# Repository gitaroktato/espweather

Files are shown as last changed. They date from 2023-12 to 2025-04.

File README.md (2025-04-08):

# An ESP8266 -based Weather Station

## Realtime Measurements
View it on ThikgSpeak (https://thingspeak.com/channels/2390966)

## Schematic
EasyEDA schematics
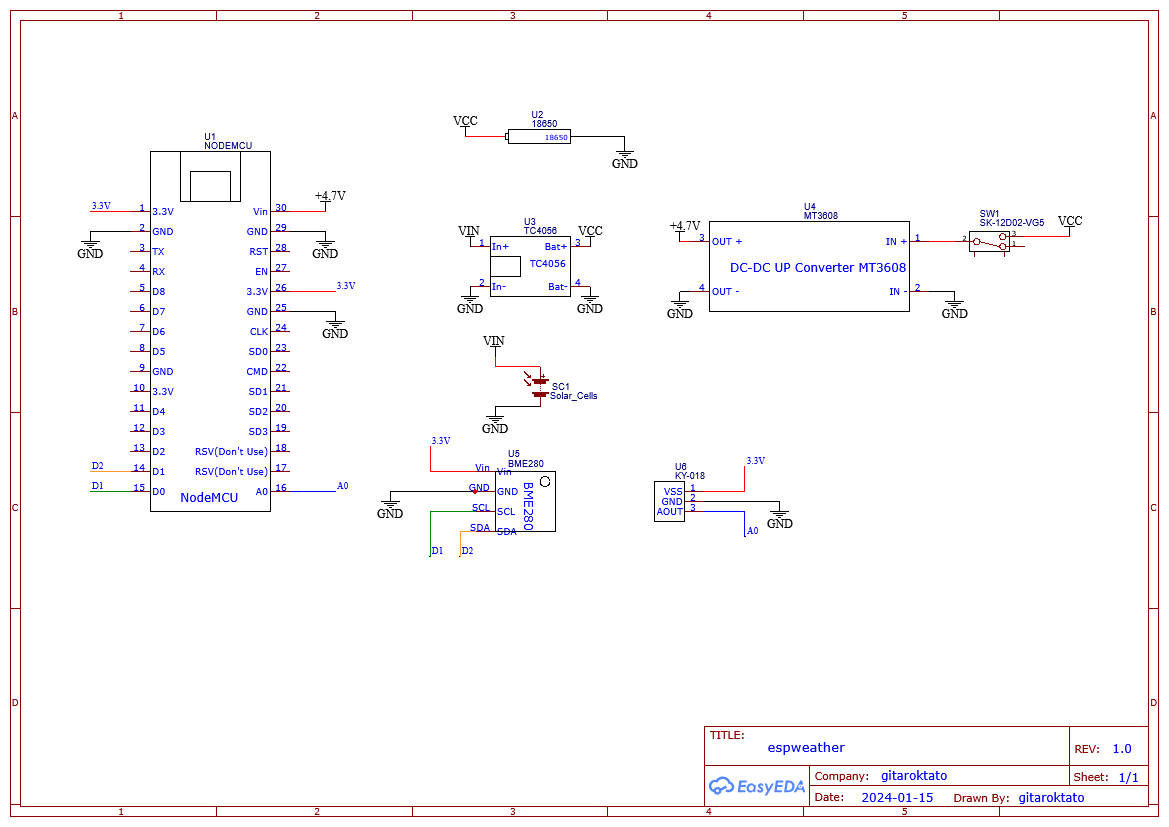
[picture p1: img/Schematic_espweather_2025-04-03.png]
schematic


Fritzing diagram
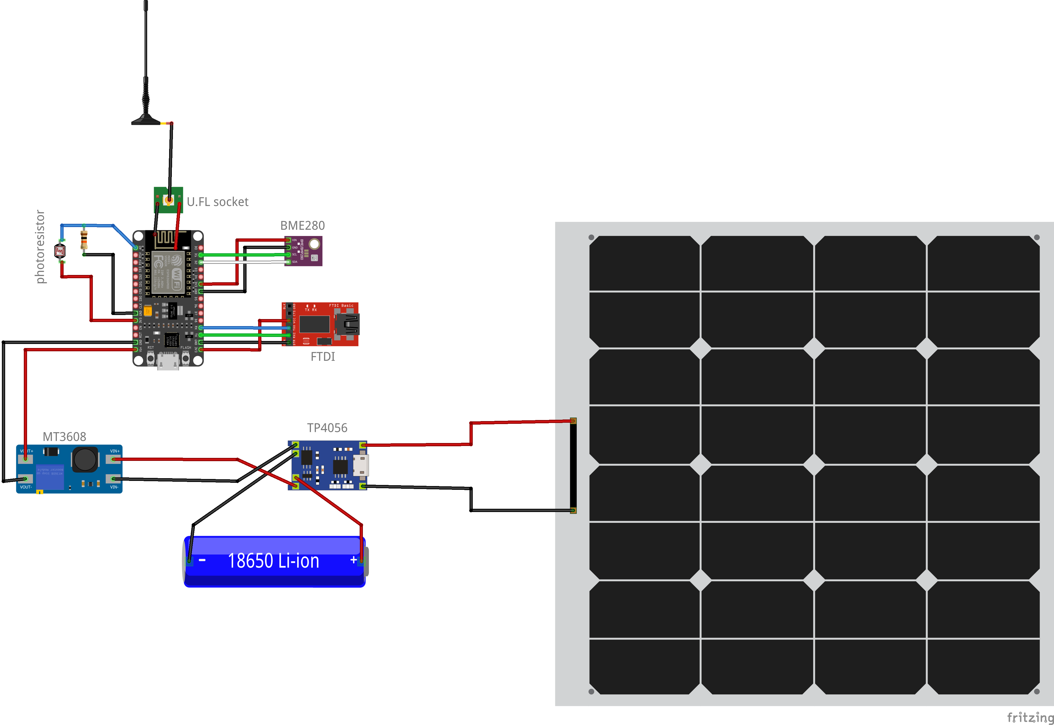
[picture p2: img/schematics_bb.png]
schematic


## Look & Feel

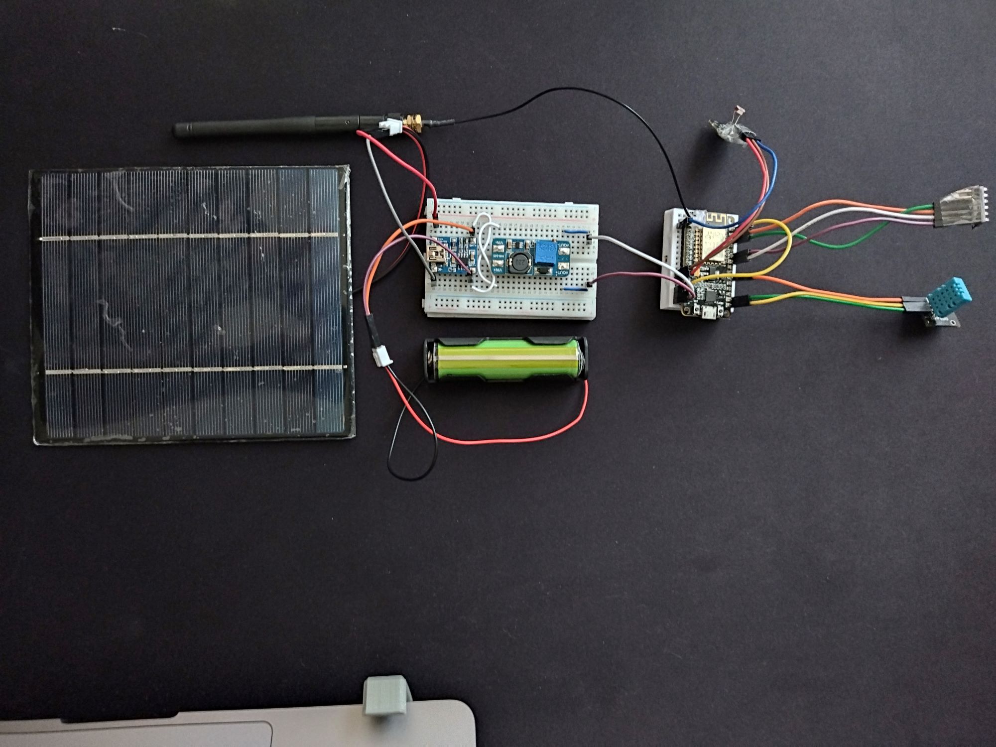
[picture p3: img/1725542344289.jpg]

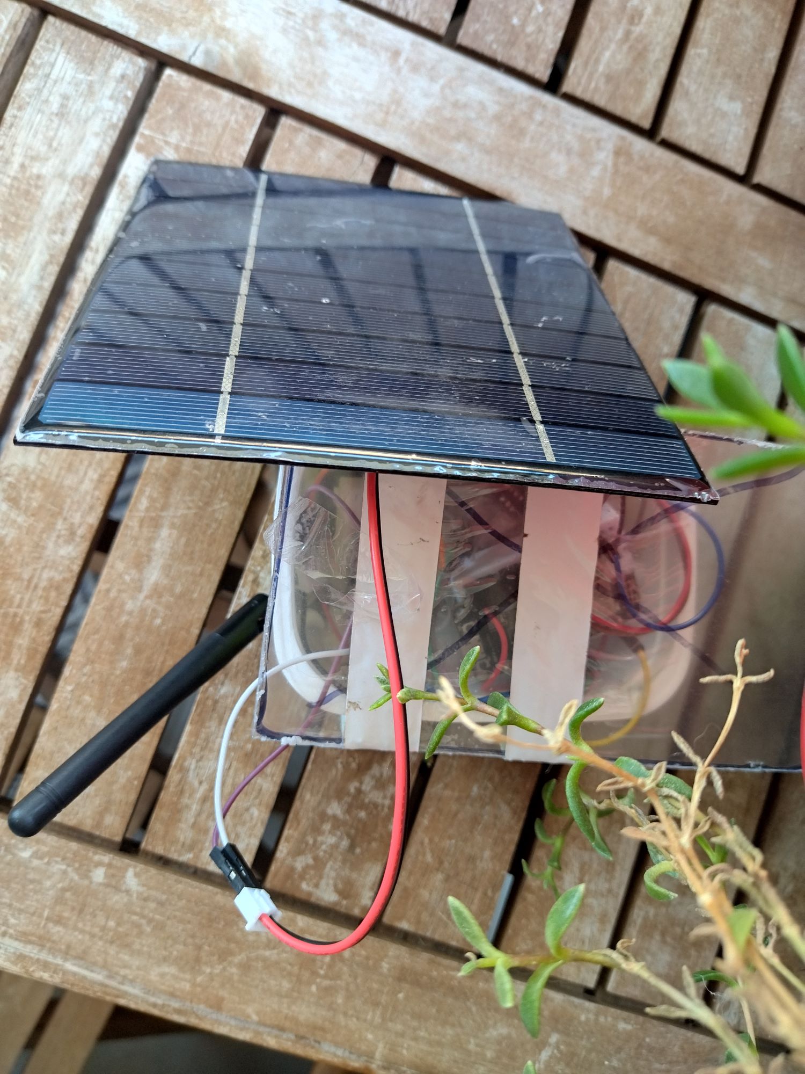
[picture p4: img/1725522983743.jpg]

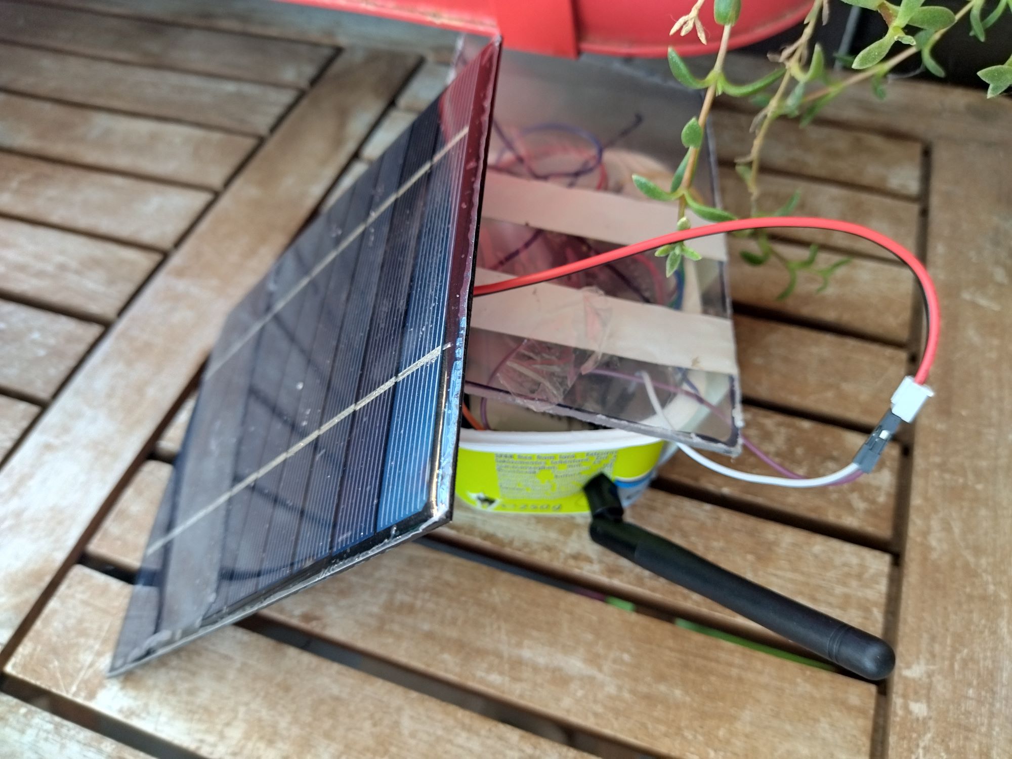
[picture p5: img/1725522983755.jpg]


## Energy Consumption and Battery Life
Powered by a [18650 battery with the capacity of 3300mAh](https://www.hestore.hu/prod_10039174.html?lang=en).

| State | Consumption | Period |
| -- | -- | -- |
| Wake - with onboard LEDs ON | 100mA | ~1s |
| Sleep - with onboard LEDs ON | 30mA | ~1s |
| Wake - with onboard LEDs OFF | 160mA | ~5s |
| Deep Sleep - with onboard LEDs OFF | 4mA | ~15 min |

### Battery life estimation
Over an hour period we expect to have 4 times `5s` spent on reporting. During these intervals the energy consumption is `160mA`.
In the remaining time we expect to consume `4mA`. This period lasts for `3600s - (4 * 5s)) = 3580s`.

The total battery consumption over an hour is around `160mA * 5s * 4` for the reporting periods, and `4mA * 3580s` for the deep sleep.
**Consumption over an hour is** `(3200mA + 14320mA) / 3600s ~= 4.86mA`

On average expected reporting time should be **28 days (3300mAh / ~4.86mA / 24h)**!

- Current reporting time without deep sleep and both LEDs blinking ~22 hrs
- Last reporting time with deep sleep ~3 days (on balcony, but suspecting continuous connection problems. See issue #12)
- Last reporting time with deep sleep ~14 days (on balcony with a step-up converter)

### Circuit Bending
#### Cutting off the onboard USB UART bridge
In order to reduce power consumption Node MCU requires hardware modifications. This is mainly due to the fact, that the CP2102 UART bridge is getting powered even if we use the 3V3 pin. The estimated power consumption is around `~15mA`. This can be done with an exacto knife.

Programming and flashing firmware for the ESP8266 can be done with an FTDI chip (see [Fritzing diagram](#schematic))

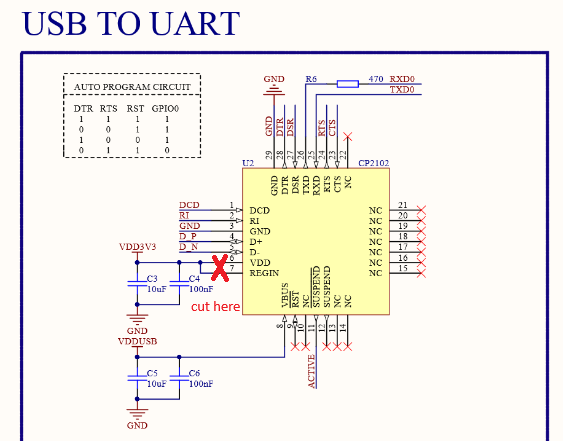
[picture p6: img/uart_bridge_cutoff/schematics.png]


First we scrape off the resin from the surface to reveal the ciruit.



Next we break the connection.



- More about this topic is available [over here](https://tinker.yeoman.digital/2016/05/29/running-nodemcu-on-a-battery-esp8266-low-power-consumption-revisited/).
- See the schematics [over here](https://github.com/nodemcu/nodemcu-devkit-v1.0/blob/master/NODEMCU_DEVKIT_V1.0.PDF).

#### External SMA antenna
Another improvement we can do is to include an external antenna. You can solder it directly, or use an U.FL connector for nicer look & feel.

If you want to solder in an U.FL socket, you need to arrange it the following way. Start with cutting off the connection for the onbard antenna.



Arrange the U.FL socket the following way:



For the direct wire connection you can secure your work usgin hot glue. See the images below:

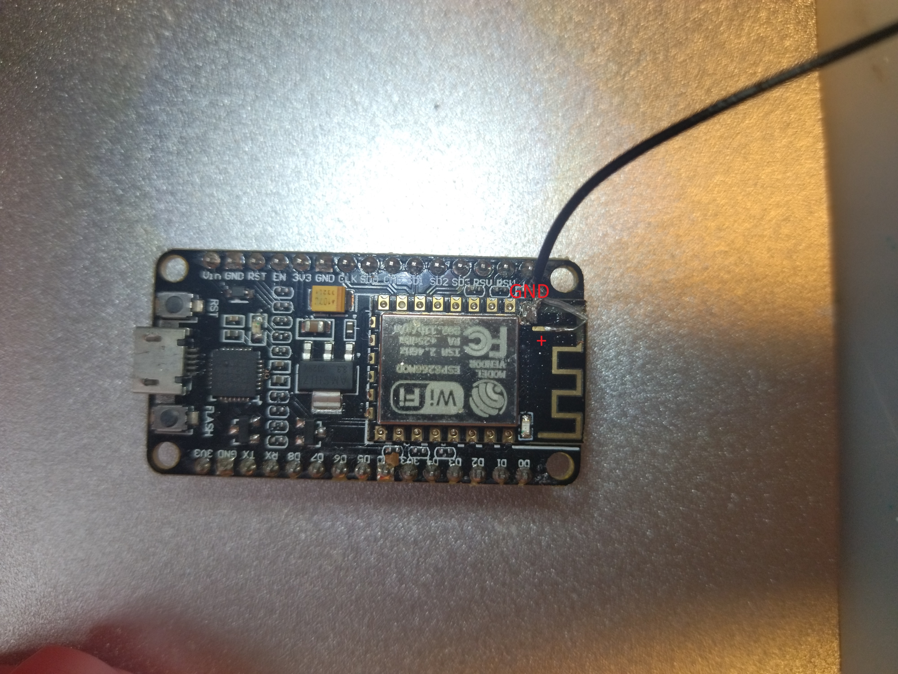
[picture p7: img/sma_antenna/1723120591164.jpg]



More about this topic is available on [YouTube](https://www.youtube.com/watch?v=RYlvXglUnGc) and on other sites, [here](https://community.home-assistant.io/t/how-to-add-an-external-antenna-to-an-esp-board/131601) and [here](https://www.hackster.io/simon-vavpotic/esp32-and-esp8266-external-antenna-f28e6b).

### Measurements
Measurements made using an oscilloscope through a shunt resistor of 1 Ohm. See the setup below:



Wake - with onboard LEDs ON shows 60mA usage on average.



Deep sleep with periodic wake times - shows `17mA` usage on average with 80mA peak. See the table above with estimated battery life.



Deep sleep after hardware modifications - shows `4mA` usage on average with 160mA peak. See the table above with estimated battery life.

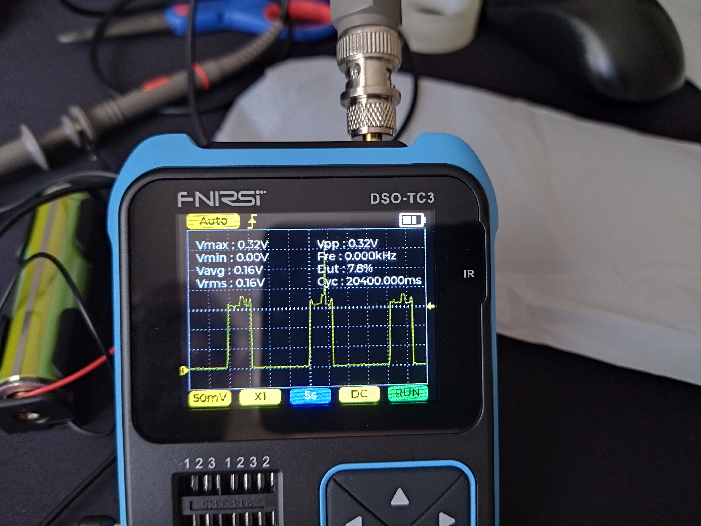
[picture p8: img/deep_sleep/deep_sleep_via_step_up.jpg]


## References

- https://randomnerdtutorials.com/esp8266-pinout-reference-gpios/
- https://randomnerdtutorials.com/esp8266-bme280-arduino-ide/
- https://arduinomodules.info/ky-015-temperature-humidity-sensor-module/
- https://nothans.com/thingspeak-tutorials/esp8266/building-the-internet-of-things-with-the-esp8266-wi-fi-module-and-thingspeak
- https://github.com/nothans/thingspeak-esp-examples/blob/master/examples/RSSI_to_ThingSpeak.ino

### 3D Designs
- https://www.thingiverse.com/thing:144665
- https://www.thingiverse.com/thing:4805867
- https://www.thingiverse.com/thing:1718334
- https://www.thingiverse.com/thing:1985125

### Powering ESP8266
- https://hackaday.io/project/167731-testing-cheap-linear-li-ion-chargers-for-solar
- https://forum.arduino.cc/t/how-to-power-esp8266-ch304-with-18650-li-ion-battery/1179338/14
- https://randomnerdtutorials.com/esp8266-voltage-regulator-lipo-and-li-ion-batteries/
- https://randomnerdtutorials.com/power-esp32-esp8266-solar-panels-battery-level-monitoring/
- https://www.youtube.com/watch?v=f2yMs-JAyQM
- https://www.youtube.com/watch?v=ttyKZnVzic4
- https://youtu.be/6DY767kQnUM?si=SXygTiLH4zx0RgAH

### Power Consumption Comparison
- https://blog.voneicken.com/2018/lp-wifi-esp-comparison/

### Deep Sleep
- https://randomnerdtutorials.com/esp8266-deep-sleep-with-arduino-ide/
- https://www.instructables.com/ESP8266-Pro-Tips
- https://arduinodiy.wordpress.com/2020/01/18/very-deepsleep-and-energy-saving-on-esp8266/

### Photocells
- https://www.mouser.com/datasheet/2/737/photocells-932884.pdf

### FTDI Upload for ESP8266
- https://community.platformio.org/t/esp32-pio-unified-debugger/4541/19

### BME280
- https://randomnerdtutorials.com/esp8266-bme280-arduino-ide

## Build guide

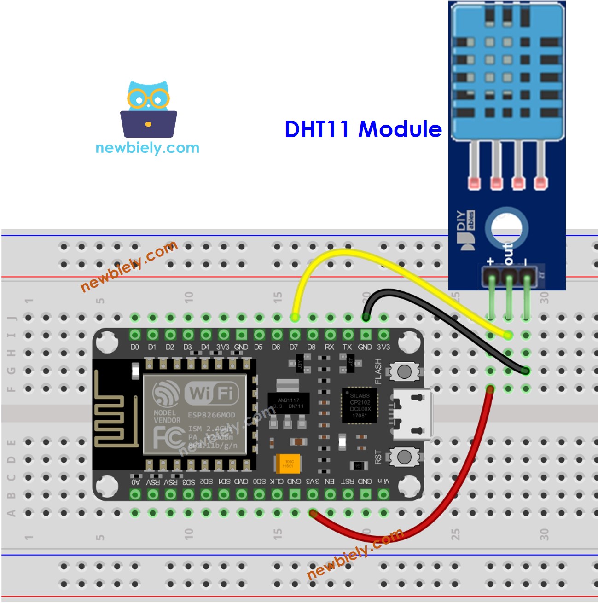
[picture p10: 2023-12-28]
img/esp8266-dht11-temperature-humudity-module-wiring-diagram.jpg

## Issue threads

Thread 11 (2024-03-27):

Fix deep sleep issue with WiFi connectivity

gitaroktato, 2024-03-27:
The WiFi seems to attempt reconnection continuously after waking up from a deep sleep.

**Things to try**
- Lower deep sleep period
- Re-evaluate WiFi connection approach

gitaroktato, 2024-08-14:
Reference guide: https://www.espressif.com/sites/default/files/9b-esp8266-low_power_solutions_en_0.pdf

gitaroktato, 2024-08-21:
Detailed post with hardware hack: https://tinker.yeoman.digital/2016/05/29/running-nodemcu-on-a-battery-esp8266-low-power-consumption-revisited/

gitaroktato, 2024-08-21:
NodeMCU schematics:
https://github.com/nodemcu/nodemcu-devkit-v1.0/blob/master/NODEMCU_DEVKIT_V1.0.PDF

Closed 2024-08-29.

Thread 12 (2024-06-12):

Add extended antenna to ESP8266 NodeMCU

gitaroktato, 2024-06-12:
https://peterneufeld.wordpress.com/2021/10/14/esp32-range-extender-antenna-modification/
https://www.youtube.com/watch?app=desktop&v=Mx0uEBPu7_8
https://community.home-assistant.io/t/how-to-add-an-external-antenna-to-an-esp-board/131601/13

SMA socket soldering:
https://www.youtube.com/watch?v=RYlvXglUnGc

Pinouts:
https://community.home-assistant.io/t/how-to-add-an-external-antenna-to-an-esp-board/131601
https://www.hackster.io/simon-vavpotic/esp32-and-esp8266-external-antenna-f28e6b

gitaroktato, 2024-08-12:
Range tests:
https://www.youtube.com/watch?v=KYLN9qH0C84

Closed 2024-08-29.

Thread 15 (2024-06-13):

Use an LDO regulator for lower deep sleep power consumption

oresztesz-margaritisz-epam, 2024-06-13:
See: https://randomnerdtutorials.com/esp8266-voltage-regulator-lipo-and-li-ion-batteries/

gitaroktato, 2024-08-12:
Interesting experiment:
https://www.youtube.com/watch?v=IYuYTfO6iOs

gitaroktato, 2024-08-13:
Check the datasheet for using the internal LDO
http://www.advanced-monolithic.com/pdf/ds1117.pdf

gitaroktato, 2025-03-31:
See [XC6206](https://product.torexsemi.com/system/files/series/xc6206.pdf) datasheet

gitaroktato, 2025-04-03:
18650 discharge capacity

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

gitaroktato, 2025-04-08:
[This example code](https://gitlab.com/diy_bloke/verydeepsleep_bme280_sendtodb/blob/5cfaa397f4a345243831fb27357382abf2de3087/%20VeryDeepSleep_BME280_sendToDB.ino) has many improvements implemented:

1. Static IP address
2. Disabling writing/reading connectivity settings to flash memory
3. Supply a WiFi channel number and a BSSID. Save it into RTC memory. See [here](https://gitlab.com/diy_bloke/verydeepsleep_bme280_sendtodb/-/blob/master/%20VeryDeepSleep_BME280_sendToDB.ino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).
4. WiFi force sleep when booting (e.g. require less milliamps on boot)
5. NOT switch on the radio by default. E.g. `WAKE_RF_DISABLED` for deep sleep.

gitaroktato, 2025-04-09:
A good article on Meshtastic about power consumption:
https://meshtastic.org/docs/hardware/solar-powered/measure-power-consumption/

gitaroktato, 2025-05-06:
WiFi power consumption:
https://www.bakke.online/index.php/2017/05/21/reducing-wifi-power-consumption-on-esp8266-part-1/

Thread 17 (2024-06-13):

Add a pressure sensor

gitaroktato, 2024-06-13:
Weather conditions often depend on air pressure. Add a pressure sensor to be able to do predictions.

https://www.hestore.hu/prod_10038750.html
https://www.hestore.hu/prod_getfile.php?id=15019

gitaroktato, 2025-03-31:
Using BME280-M

https://randomnerdtutorials.com/esp8266-bme280-arduino-ide/

Closed 2025-04-08.

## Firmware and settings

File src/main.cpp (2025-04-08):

#include <Arduino.h>

/*
 ESP8266 BME280 --> ThingSpeak Channel
 
 This sketch sends the BME280 temperature/humidity of an ESP8266 to a ThingSpeak
 channel using the ThingSpeak API (https://www.mathworks.com/help/thingspeak).
 
 Requirements:
 
   * ESP8266 Wi-Fi Device
   * Arduino 1.8.8+ IDE
   * BME280 sensor board
   * Additional Boards URL: http://arduino.esp8266.com/stable/package_esp8266com_index.json
   * Library: esp8266 by ESP8266 Community
   * Library: ThingSpeak by MathWorks
 
 ThingSpeak Setup:
 
   * Sign Up for New User Account - https://thingspeak.com/users/sign_up
   * Create a new Channel by selecting Channels, My Channels, and then New Channel
   * Enable one field
   * Enter SECRET_CH_ID in "secrets.h"
   * Enter SECRET_WRITE_APIKEY in "secrets.h"

 Setup Wi-Fi:
  * Enter SECRET_SSID in "secrets.h"
  * Enter SECRET_PASS in "secrets.h"
  
 Tutorial: http://nothans.com/measure-wi-fi-signal-levels-with-the-esp8266-and-thingspeak
   
 Created: Feb 1, 2017 by Hans Scharler (http://nothans.com)
*/

#include <Adafruit_BME280.h>
#include <ESP8266WiFi.h>

#include "ThingSpeak.h"
#include "secrets.h"

#define SERIAL_BAUDRATE 9600
#define ONBOARD_LED 16
#define ESP8266_LED 2

#define SEALEVELPRESSURE_HPA (1013.25)

#define PHOTORESISTOR_PIN A0
// Report to ThingSpeak or not
#define REPORT_ON
// Use onbard LEDs to display current state or not
// #define LED_STATE_ON

#ifdef REPORT_ON
// Period in microseconds for channel update. Should be around 10-15 minutes
#define PERIOD 15 * 60 * 1000 * 1000
#else
// Period in microseconds for troubleshooting. Should be around 15 seconds
#define PERIOD 15 * 1000 * 1000
#endif

// ThingSpeak channel and API key
unsigned long myChannelNumber = SECRET_CH_ID;
const char * myWriteAPIKey = SECRET_WRITE_APIKEY;

char ssid[] = SECRET_SSID;   // your network SSID (name)
char pass[] = SECRET_PASS;   // your network password
int keyIndex = 0;            // your network key index number (needed only for WEP)
WiFiClient  client;

Adafruit_BME280 bme; // I2C

bool ledState = 0x0;

/**
 * Writes field to the specified ThingSpeak channel
*/
void writeFieldToThingSpeakChannel(unsigned int fieldId, float value) {
  int httpCode = ThingSpeak.writeField(myChannelNumber, fieldId, value, myWriteAPIKey);
  if (httpCode == 200) {
    Serial.println("Field #" + String(fieldId) + " write successful.");
  } else {
    Serial.println("Problem writing to field #" + String(fieldId) + " - HTTP error code " + String(httpCode));
  }
}

void setup() {
  // Can't use with deep sleep
  // pinMode(ONBOARD_LED, OUTPUT);
  pinMode(ESP8266_LED, OUTPUT);

  Serial.begin(SERIAL_BAUDRATE);
  delay(100);

#ifdef REPORT_ON
  WiFi.mode(WIFI_STA);
  ThingSpeak.begin(client);
#else
  WiFi.mode(WIFI_OFF);
#endif

  bool bme_status;
	bme_status = bme.begin(0x76);		//Begin the sensor
  if (!bme_status) {
    Serial.println("Could not find a valid BME280 sensor, check wiring!");
    while (1);
  }
}

void loop() {

  #ifdef REPORT_ON
    // Connect or reconnect to WiFi
    if (WiFi.status() != WL_CONNECTED) {
      Serial.print("Attempting to connect to SSID: ");
      Serial.println(SECRET_SSID);
      // Turn on all LEDs
      // Can't use with deep sleep
      // digitalWrite(ONBOARD_LED, HIGH);
      digitalWrite(ESP8266_LED, HIGH);
      
      while (WiFi.status() != WL_CONNECTED) {
        WiFi.begin(ssid, pass); // Connect to WPA/WPA2 network. Change this line if using open or WEP network
        Serial.print(".");
        // Switch one LED
        ledState = !ledState;
        digitalWrite(ESP8266_LED, ledState);
        delay(5000);
      }
      Serial.println("\nConnected.");
    }
  #endif

  // Turn off all LEDs
  // Can't use with deep sleep
  // digitalWrite(ONBOARD_LED, LOW);
  digitalWrite(ESP8266_LED, LOW);

  // Measure Signal Strength (RSSI) of Wi-Fi connection
  #ifdef REPORT_ON
    long rssi = WiFi.RSSI();
    Serial.println("RSSI: " + String(rssi) + " dB");
  #endif
  // Getting Vcc from board
  float Vcc = (float)ESP.getVcc() / 65535 * 100;
  Serial.println("Vcc: " + String(Vcc) + "%");

  // BE280 read humidity
  float humi  = bme.readHumidity();
  // BE280 read temperature in Celsius
  float tempC = bme.readTemperature();
  // BMP280 reads
  float airPressure = bme.readPressure() / 100.0F;
  float altitude = bme.readAltitude(SEALEVELPRESSURE_HPA);

  // read photoresistor value
  float lux = analogRead(PHOTORESISTOR_PIN);

  // check whether the reading is successful or not
  if ( isnan(tempC) ||  isnan(humi)) {
    Serial.println("Failed to read from BME sensor!");
  } else {
    Serial.print("Humidity: " + String(humi) + "%");
    Serial.print("  |  ");
    Serial.println("Temperature: " + String(tempC) + "°C");
  }

  // check whether the reading is successful or not
  if ( isnan(airPressure) ||  isnan(altitude)) {
    Serial.println("Failed to read from BME280 sensor!");
  } else {
    Serial.print("Air pressure: " + String(airPressure) + " hPa"); 
    Serial.print("  |  ");
    Serial.println("Altitude: " + String(altitude) + " m");
  }

  if ( isnan(lux) ) {
    Serial.println("Failed to read from photoresistor!");
  } else {
    Serial.println(String(lux) + " lux");
  }

  #ifdef REPORT_ON
    ThingSpeak.setField(1, tempC);
    ThingSpeak.setField(2, humi);
    ThingSpeak.setField(3, lux);
    ThingSpeak.setField(4, Vcc);
    ThingSpeak.setField(5, rssi);
    ThingSpeak.setField(6, airPressure);
    ThingSpeak.setField(7, altitude);
    
    int httpCode = ThingSpeak.writeFields(myChannelNumber, myWriteAPIKey);
    if (httpCode == 200) {
      Serial.println("Channel write successful.");
    } else {
      Serial.println("Problem writing to channel - HTTP error code " + String(httpCode));
    }
  #endif

  #ifdef LED_STATE_ON
    // Switch two onboard LEDs
    ledState = !ledState;
    digitalWrite(ONBOARD_LED, ledState);
    digitalWrite(ESP8266_LED, !ledState);
  #endif

  // Wait to update the channel again
  Serial.println("Now on deep sleep for " + String(PERIOD / (1000 * 1000)) + " sec");
  // Normal sleep in milliseconds
  // delay(5 * 1000);
  // Deep sleep in microseconds
  ESP.deepSleep(PERIOD);
}

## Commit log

2024-01-06 feat: Added light sensor
2024-01-09 docs: Added wiring diagram
2024-01-21 feat: Schematic and Vcc measurement
2024-01-21 feat: Added battery option with look&feel
2024-01-21 feat: Fixing wiring diagram
2024-06-12 feat: Deep sleep with logs fixed and energy save
    [main.cpp]
2024-06-13 docs: Added power consumption comparison to README.md
2024-06-24 docs: More info on running ESP8266 on battery
2024-08-29 feat: Documenting external antenna
2024-09-05 feat: Updated wiring diagrams
    [schematics.fzz]
2024-09-05 feat: Added pressure sensor code
2024-09-05 feat: Updates with pressure sensor
2025-04-01 fix: Adding back humidity report
    [main.cpp]
2025-04-01 docs: Adding pressure sensor to docs
2025-04-03 docs: Adding schematics for BME280
    [schematics.fzz]
2025-04-03 docs: Removing DHT-11 and adding schematics
    [schematics.fzz]
